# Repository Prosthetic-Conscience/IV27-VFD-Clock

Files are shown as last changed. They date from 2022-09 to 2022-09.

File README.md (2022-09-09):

# IV27-VFD-Clock

This project uses an obscure Soviet era vacuum flourescent tube (IV27m). The intitial design idea was for a clock that looked like a scifi movie explosive device (think 80's cheesy movie bombs)119057616_10224747282215496_3767550900032111040_n

The first step was decoding the tube pinouts
119114848_10224747282415501_1258083057988973816_n

These pins were decoded manually as the little extant documentation is in cyrillic for the most part
118980220_10224747281735484_5323936303906219770_n
119069551_10224747281895488_4151508991232845230_n

From there a main PCB and end cap PCBs were designed

119095870_10224746568717659_4204971245167933345_n
119109238_10224746568877663_8699561781063773989_n

The boards were spun using EaglePCB and built by JLPCB
118980679_10224746586598106_3718895178650649830_n
119049793_10224746586518104_891389979846681961_n

From there assembly, feature expansion and done! It was modified to use an NTP time server, and uses the excellent WIFI manager arduino library. When the device boots and doesn't find a known SSID it rebootsd with a webserver running, and then scans for local SSIDs and then lets you select the correct one, load the password, and then if it connects successfully will reboot and connect itself.
119061632_10224746569037667_7521624622622321505_n
119061191_10224746569237672_3589316026076861871_n

Future plans for it involve using Geolocation to automatically set the timezone (versus the current hardcoded Central time) so it can be a bit more flexible.
119666221_10224820562527458_4136581820536597280_n (1)

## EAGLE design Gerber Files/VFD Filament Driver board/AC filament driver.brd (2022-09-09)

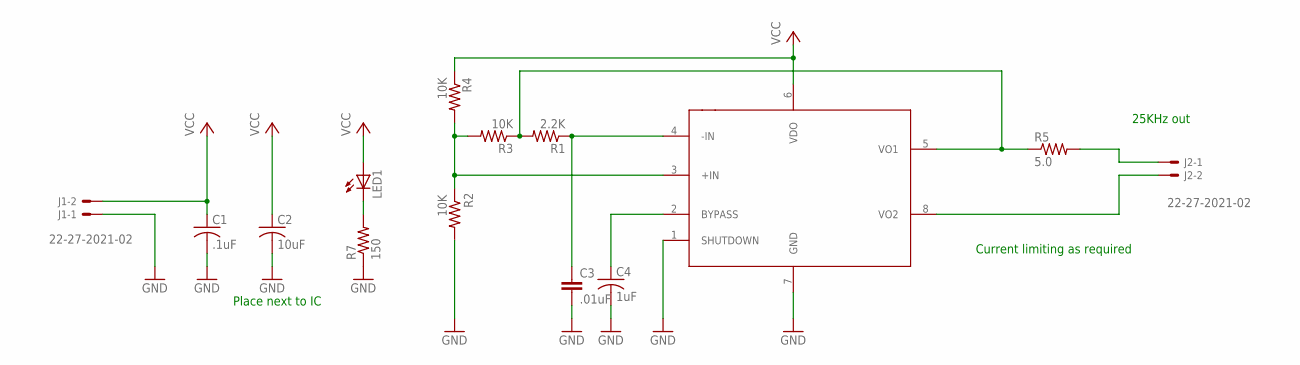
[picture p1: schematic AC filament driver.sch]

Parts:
C1: .1uF; C050-024X044
C2: 10uF; C025-060X050
C3: .01uF; C0805
C4: 1uF; C025-060X050
J1, J2: 22-27-2021-02; 6410-02
LED1: LEDCHIP-LED0805; CHIP-LED0805
R1: 2.2K; R0805
R2, R3, R4: 10K; R0805
R5: 5.0; R0805
R7: 150; R0805
U1: LM9022; SOIC127P600X175-8N

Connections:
GND: C1.2, C2.2, C3.2, C4.2, J1.1, R2.2, R7.1, U1.1 (SHUTDOWN), U1.7 (GND)
unnamed: LED1.C, R7.2
unnamed: R2.1, R3.2, R4.2, U1.3 (+IN)
unnamed: R1.2, R3.1, R5.1, U1.5 (VO1)
unnamed: C3.1, R1.1, U1.4 (-IN)
unnamed: C4.1, U1.2 (BYPASS)
unnamed: J2.1, R5.2
unnamed: J2.2, U1.8 (VO2)
VCC: C1.1, C2.1, J1.2, LED1.A, R4.1, U1.6 (VDO)

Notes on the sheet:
Current limiting as required
25KHz out
Place next to IC

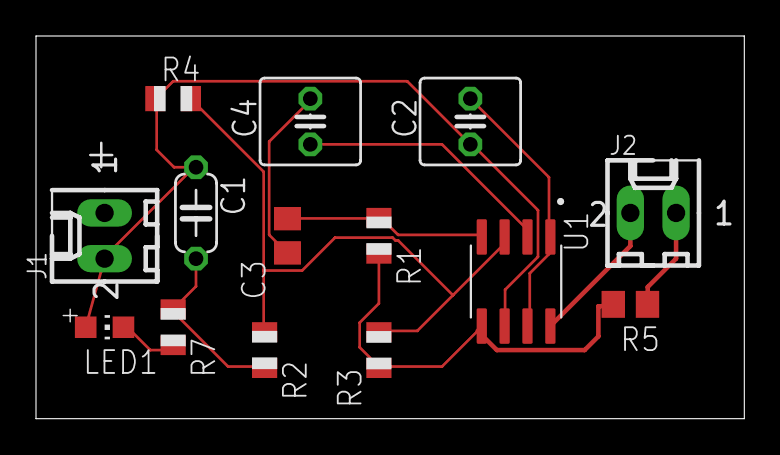
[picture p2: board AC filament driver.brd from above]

Board: 2 copper layers, 39.4 x 21.3 mm, 14 parts (0 on the bottom side), 9 nets.

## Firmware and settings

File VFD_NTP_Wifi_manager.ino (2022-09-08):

#include <ArduinoOTA.h>
#include <FS.h>                   //this needs to be first, or it all crashes and burns...
#include <ESP8266WiFi.h>          //https://github.com/esp8266/Arduino
//needed for library
#include <DNSServer.h>
#include <ESP8266WebServer.h>
#include <WiFiManager.h>          //https://github.com/tzapu/WiFiManager
#include <time.h>               // time() ctime()
#include <WiFiUdp.h>
#include <NTPClient.h>
#include <Timezone.h> 

//I/O config
const int clk = D1;
const int load = D2;
const int din = D3;
const int blank = D4;

//Button config
const int tdSwitch = D7;
boolean dateTimeState = LOW; //LOW is time, HIGH is date

//holds previous milli() value for once a second update
unsigned long previousMillis = 0;
//NTP client config
const long interval = 1000; 
const long utcOffsetInSeconds = -21600;

// Define NTP Client to get time
WiFiUDP ntpUDP;

//TODO add utc as constants, list on wifi manger page, save in EEPROM
//NTPClient timeClient(UDP object, NTP source, utcOffsetInSeconds,update interval); //TODO, look at this offset
NTPClient timeClient(ntpUDP, "pool.ntp.org", utcOffsetInSeconds,60000);

// US Central Time Zone (Chicago)
TimeChangeRule CDT = {"CDT", Second, Sun, Mar, 2, 60};    // Daylight time = UTC - 5 hours /-300
TimeChangeRule CST = {"CST", First, Sun, Nov, 2,  0};     // Standard time = UTC - 6 hours/-360
Timezone Eastern(CDT, CST);

// If TimeChangeRules are already stored in EEPROM, comment out the three
// lines above and uncomment the line below.
//Timezone myTZ(100);       // assumes rules stored at EEPROM address 100
TimeChangeRule *tcr;        // pointer to the time change rule, use to get TZ abbrev

time_t t_Utc;
time_t t_Local;

void shiftOutFour(uint8_t dataPin, uint8_t clockPin, uint8_t bitOrder, byte val)
{

uint8_t i;

for (i = 0; i < 4; i++)  {
     if (bitOrder == LSBFIRST)
           digitalWrite(dataPin, !!(val & (1 << i)));
     else      
           digitalWrite(dataPin, !!(val & (1 << (7 - i))));
           
     digitalWrite(clockPin, HIGH);
     digitalWrite(clockPin, LOW);            
  }
}
const byte numMatrix[10] = {
  //segments
  //g,f,e,d,c,b,a,dp
  0xFC, //ZERO
  0x60, //ONE //00001100  
  0xDA, //TWO 0xB6,
  0xF2, //THREE
  0x66, //FOUR
  0xB6, //FIVE
  0xBE, //SIX
  0xE0, //SEVEN
  0xFE, //EIGHT
  0xE6 //NINE
};

const byte numMatrixDec[10] = {
  //segments
  //g,f,e,d,c,b,a,dp
  0xFD, //ZERO
  0x61, //ONE //00001100  
  0xDB, //TWO 0xB6,
  0xF3, //THREE
  0x67, //FOUR
  0xB7, //FIVE
  0xBF, //SIX
  0xE1, //SEVEN
  0xFF, //EIGHT
  0xE7 //NINE
};
//first address bank
const byte gridArray[15] = {
0x00,//{0,0,0,0,0,0,0,0,0,0,0,0}; // Blank display 
0x01, //{0,0,0,0,0,0,0,0,0,0,0,1}; // Grid 1
0x02, //{0,0,0,0,0,0,0,0,0,0,1,0}; // Grid 2
0x04,//{0,0,0,0,0,0,0,0,0,1,0,0}; // Grid 3 
0x08,//{0,0,0,0,0,0,0,0,1,0,0,0}; // Grid 4
0x10,//{0,0,0,0,0,0,0,1,0,0,0,0}; // Grid 5
0x20,//{0,0,0,0,0,0,1,0,0,0,0,0}; // Grid 6
0x40,//{0,0,0,0,0,1,0,0,0,0,0,0}; // Grid 7
0x80,//{0,0,0,0,1,0,0,0,0,0,0,0}; // Grid 8
0x00,//{0,0,0,0,0,0,0,0,0,0,0,0}; // Blank Grid 9
0x00,//{0,0,0,0,0,0,0,0,0,0,0,0}; // Blank Grid 10
0x00,//{0,0,0,0,0,0,0,0,0,0,0,0}; // Blank Grid 11
0x00,//{0,0,0,0,0,0,0,0,0,0,0,0}; // Blank Grid 12
0x00,//{0,0,0,0,0,0,0,0,0,0,0,0}; // Blank Grid 13
0x00//{0,0,0,0,0,0,0,0,0,0,0,0}; // Blank Grid 14
};
//Last address bank
const byte gridArrayHigh[15] = {
0x00,//{0,0,0,0,0,0,0,0,0,0,0,0}; // Blank display   
0x00,//{0,0,0,0,0,0,0,0,0,0,0,0}; // Blank  Grid 1
0x00,//{0,0,0,0,0,0,0,0,0,0,0,0}; // Blank Grid 2
0x00,//{0,0,0,0,0,0,0,0,0,0,0,0}; // Blank Grid 3 
0x00,//{0,0,0,0,0,0,0,0,0,0,0,0}; // Blank Grid 4
0x00,//{0,0,0,0,0,0,0,0,0,0,0,0}; // Blank Grid 5
0x00,//{0,0,0,0,0,0,0,0,0,0,0,0}; // Blank Grid 6
0x00,//{0,0,0,0,0,0,0,0,0,0,0,0}; // Blank Grid 7
0x00,//{0,0,0,0,0,0,0,0,0,0,0,0}; // Blank Grid 8
0x01,//{0,0,0,1,0,0,0,0,0,0,0,1}; // Grid 9
0x02,//{0,0,1,0,0,0,0,0,0,0,1,0}; // Grid 10
0x04,//{0,1,0,0,0,0,0,0,0,1,0,0}; // Grid 11
0x08, //{1,0,0,0,0,0,0,0,1,0,0,0}; // Grid 12
0x10,//{0,0,0,0,0,0,0,0,0,0,0,0}; // Grid 13
0x20,//{0,0,0,0,0,0,0,0,0,0,0,0}; // Grid 14
};

void setup() {
Serial.begin(115200);
pinMode(din, OUTPUT);
pinMode(load, OUTPUT);
pinMode(clk, OUTPUT);
pinMode(blank, OUTPUT);
pinMode(tdSwitch, INPUT_PULLUP);
digitalWrite(clk, LOW);
digitalWrite(load, LOW);
digitalWrite(din, LOW); 
digitalWrite(blank, LOW);

//WiFiManager
//Local intialization. Once its business is done, there is no need to keep it around
WiFiManager wifiManager;

//exit after config instead of connecting
wifiManager.setBreakAfterConfig(true);

//reset settings - for testing
//wifiManager.resetSettings();


//tries to connect to last known settings
//if it does not connect it starts an access point with the specified name
//here  "AutoConnectAP" with password "password"
//and goes into a blocking loop awaiting configuration
  if (!wifiManager.autoConnect("AutoConnectAP", "")) {
    Serial.println("failed to connect, we should reset and see if it connects");
    delay(3000);
    ESP.reset();
    delay(5000);
  }
  
//if you get here you have connected to the WiFi
Serial.println("");
Serial.println("WiFi connected");
Serial.println("IP address: ");
Serial.println(WiFi.localIP());
timeClient.begin();
delay(1000);
timeClient.update();
delay(1000);

t_Utc = timeClient.getEpochTime();
Serial.print("UTC time from NTP set to : ");
Serial.println(t_Utc);

//setTime(01, 55, 00, 11, 3, 2012);        //another way to set the time (hr,min,sec,day,mnth,yr)
//setTime(timeClient.getHours(),timeClient.getMinutes(),timeClient.getSeconds(),timeClient.getDay()
Serial.print("UTC local time set to : ");
t_Local = Eastern.toLocal(t_Utc);
Serial.println(t_Local);

Serial.print("Current time set to ");
Serial.print(hour(t_Local));
Serial.print(":");
Serial.print(minute(t_Local));
Serial.print(":");
Serial.println(second(t_Local)); 
timeClient.update(); 
}

void loop() {
unsigned long currentMillis = millis();
//Update time object once a second
if (currentMillis - previousMillis >= interval) 
    {
    // save the last time was called
    previousMillis = currentMillis;     
    //timeClient.update(); //should add a second TODO: research library
    t_Local = Eastern.toLocal(timeClient.getEpochTime());  
    if(digitalRead(tdSwitch) == LOW)
      {
      if(dateTimeState == true) 
        {
        dateTimeState = false;      
        }
      else if(dateTimeState == false)
        {
        dateTimeState = true;      
        }  
      } 
  timeClient.update();      
  }     
        
//Time code block    
if(dateTimeState == false) 
  {
  int hour_first = (hour(t_Local)/10);
  int hour_second = (hour(t_Local) % 10);
  
  digitalWrite(load, LOW);  
  shiftOut(din, clk, LSBFIRST, numMatrix[hour_first]);
  shiftOut(din, clk, LSBFIRST, 0x04); //55 01010101
  shiftOutFour(din, clk, LSBFIRST, 0x00);
  digitalWrite(load, HIGH);
  delay(3);

  digitalWrite(load, LOW);  
  shiftOut(din, clk, LSBFIRST, numMatrix[hour_second]);
  shiftOut(din, clk, LSBFIRST, 0x08); //55 01010101
  shiftOutFour(din, clk, LSBFIRST, 0x00);
  digitalWrite(load, HIGH);  
  delay(3);

  int min_first = (minute(t_Local)/10);
  int min_second = (minute(t_Local) % 10);
  
  digitalWrite(load, LOW);  
  shiftOut(din, clk, LSBFIRST, numMatrix[min_first]);
  shiftOut(din, clk, LSBFIRST, 0x20); //55 01010101
  shiftOutFour(din, clk, LSBFIRST, 0x00);
  digitalWrite(load, HIGH);  
  delay(3);

  digitalWrite(load, LOW);  
  shiftOut(din, clk, LSBFIRST, numMatrix[min_second]);
  shiftOut(din, clk, LSBFIRST, 0x40); //55 01010101
  shiftOutFour(din, clk, LSBFIRST, 0x00);
  digitalWrite(load, HIGH);  
  delay(3);

  int sec_first = (second(t_Local)/10);
  int sec_second = (second(t_Local) % 10);
  
  digitalWrite(load, LOW);  
  shiftOut(din, clk, LSBFIRST, numMatrix[sec_first]);
  shiftOut(din, clk, LSBFIRST, 0x00); //55 01010101
  shiftOutFour(din, clk, LSBFIRST, 0x01);
  digitalWrite(load, HIGH);  
  delay(3);

  digitalWrite(load, LOW);  
  shiftOut(din, clk, LSBFIRST, numMatrix[sec_second]);
  shiftOut(din, clk, LSBFIRST, 0x00); //55 01010101
  shiftOutFour(din, clk, LSBFIRST, 0x02);
  digitalWrite(load, HIGH);  
  delay(3); 
  }
//Year Code block
if(dateTimeState == true) 
  {
  //Month section
  int month_first = (month(t_Local)/10);
  int month_second = (month(t_Local) % 10);
  
  digitalWrite(load, LOW);  
  shiftOut(din, clk, LSBFIRST, numMatrix[month_first]);
  shiftOut(din, clk, LSBFIRST, 0x02); //55 01010101
  shiftOutFour(din, clk, LSBFIRST, 0x00);
  digitalWrite(load, HIGH);
  delay(2);

  digitalWrite(load, LOW);  
  shiftOut(din, clk, LSBFIRST, numMatrix[month_second]);
  shiftOut(din, clk, LSBFIRST, 0x04); //55 01010101
  shiftOutFour(din, clk, LSBFIRST, 0x00);
  digitalWrite(load, HIGH);  
  delay(2);

  digitalWrite(load, LOW);  
  shiftOut(din, clk, LSBFIRST, 0x02); // write "-" character
  shiftOut(din, clk, LSBFIRST, 0x08); //55 01010101
  shiftOutFour(din, clk, LSBFIRST, 0x00);
  digitalWrite(load, HIGH);  
  delay(2);
  
  //Day section
  int day_first = (day(t_Local)/10);
  int day_second = (day(t_Local) % 10);
  
  digitalWrite(load, LOW);  
  shiftOut(din, clk, LSBFIRST, numMatrix[day_first]);
  shiftOut(din, clk, LSBFIRST, 0x10); //55 01010101
  shiftOutFour(din, clk, LSBFIRST, 0x00);
  digitalWrite(load, HIGH);  
  delay(2);

  digitalWrite(load, LOW);  
  shiftOut(din, clk, LSBFIRST, numMatrix[day_second]);
  shiftOut(din, clk, LSBFIRST, 0x20); //55 01010101
  shiftOutFour(din, clk, LSBFIRST, 0x00);
  digitalWrite(load, HIGH);  
  delay(2);

  digitalWrite(load, LOW);  
  shiftOut(din, clk, LSBFIRST, 0x02); // write "-" character
  shiftOut(din, clk, LSBFIRST, 0x40); //55 01010101
  shiftOutFour(din, clk, LSBFIRST, 0x00);
  digitalWrite(load, HIGH);  
  delay(2);

  //Year section
  int year_first = (year(t_Local)/1000 % 10);
  int year_second = (year(t_Local) /100 % 10);
  int year_third = (year(t_Local)/10 % 10);
  int year_fourth = (year(t_Local) % 10);
  
  digitalWrite(load, LOW);  
  shiftOut(din, clk, LSBFIRST, numMatrix[year_first]);
  shiftOut(din, clk, LSBFIRST, 0x80); //55 01010101
  shiftOutFour(din, clk, LSBFIRST, 0x00);
  digitalWrite(load, HIGH);  
  delay(2);

  digitalWrite(load, LOW);  
  shiftOut(din, clk, LSBFIRST, numMatrix[year_second]);
  shiftOut(din, clk, LSBFIRST, 0x00); //55 01010101
  shiftOutFour(din, clk, LSBFIRST, 0x01);
  digitalWrite(load, HIGH);  
  delay(2);

  digitalWrite(load, LOW);  
  shiftOut(din, clk, LSBFIRST, numMatrix[year_third]);
  shiftOut(din, clk, LSBFIRST, 0x00); //55 01010101
  shiftOutFour(din, clk, LSBFIRST, 0x02);
  digitalWrite(load, HIGH);  
  delay(2);

  digitalWrite(load, LOW);  
  shiftOut(din, clk, LSBFIRST, numMatrix[year_fourth]);
  shiftOut(din, clk, LSBFIRST, 0x00); //55 01010101
  shiftOutFour(din, clk, LSBFIRST, 0x04);
  digitalWrite(load, HIGH);  
  delay(2);  
  }  
}
